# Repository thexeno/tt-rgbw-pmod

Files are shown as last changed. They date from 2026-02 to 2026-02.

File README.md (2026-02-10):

# tt-rgbw-pmod
An overkill PMOD to handle an RGBW LED for experimenting with the color rendering of the [thexeno/tt08-rgbw-controller](https://github.com/thexeno/tt08-rgbw-controller/ "tt08-rgbw-controller") ASIC. 
This PMOD matches with the [TinyTapeout/tt-demo-pcb](https://github.com/TinyTapeout/tt-demo-pcb "tt-demo-pcb"). These links are referred to as the "ASIC documentation".

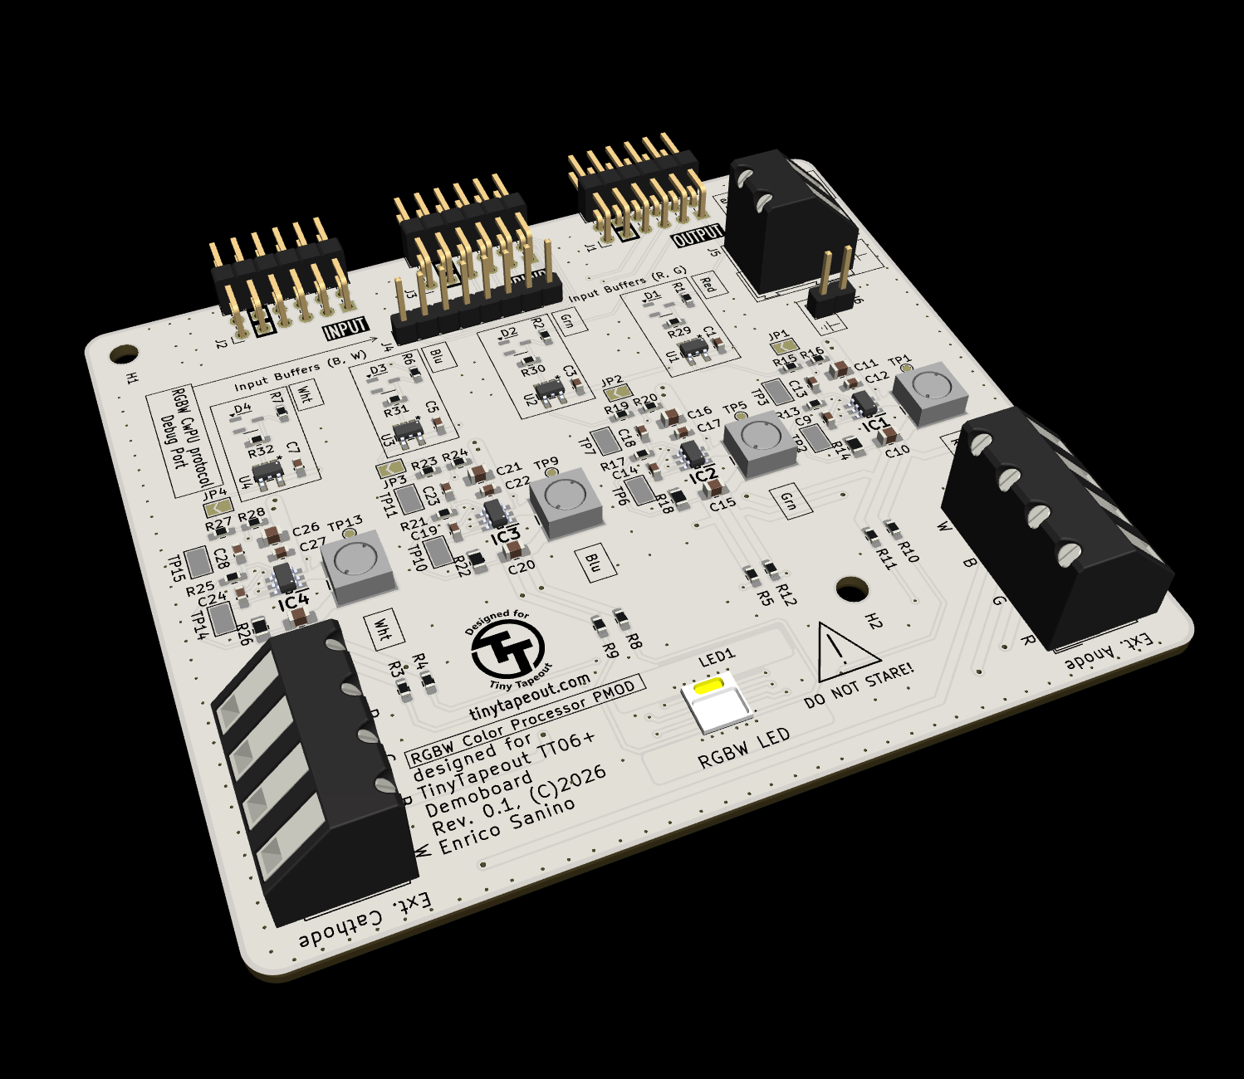
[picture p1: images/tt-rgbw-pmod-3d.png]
tt-rgbw-pmod board The RGBW PMOD board


### <p align="center"> PREVIEW: https://www.youtube.com/watch?v=X-74kIeId4A </p>

  <div align="center">
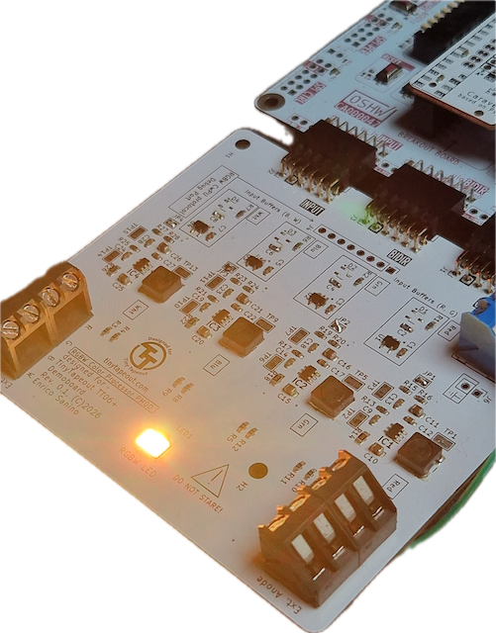
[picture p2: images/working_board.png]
  
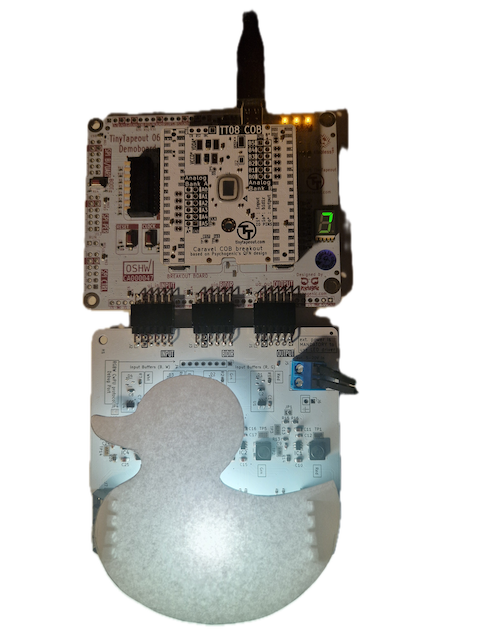
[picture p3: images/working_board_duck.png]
  
  <br>
  </div>

## Overview

This PMOD board provides high-power LED driver capabilities for the tt08-rgbw-controller ASIC, featuring four independent channels for RGBW LED control with both digital PWM and analog dimming modes.

## Pinout

### PWM inputs (inputs PMOD side, outputs ASIC side)

| Pmod | TinyTapeout | Function | Note |
|---|---|---|---|
| OUTPUT1 | uo[0] | Red PWM input | Input impedance 100 kΩ|
| OUTPUT2 | uo[1] | Green PWM input | Input impedance 100 kΩ|
| OUTPUT3 | uo[2] | Blue PWM input  | Input impedance 100 kΩ|
| OUTPUT4 | uo[3] | White PWM input | Input impedance 100 kΩ|
| OUTPUT5 - 8 | uo[4:7] | Not connected | |

### Inputs ASIC side

All "INPUT" pins are disconnected on the PMOD, not used. But the ASIC and the Demoboard are using them for the SPI communication, so signals are present if probed. See ASIC documentation.

### Colorwheel Debug Port

This applies only if enabled, see ASIC documentation.

| Pmod | TinyTapeout | Function | Note |
|---|---|---|---|
| BIDIR1 | uio_out[0] | CwPU register bit 0 |  |
| BIDIR2 | uio_out[1] | CwPU register bit 1 | |
| BIDIR3 | uio_out[2] | CwPU register bit 2  | |
| BIDIR4 | uio_out[3] | CwPU register bit 3 | |
| BIDIR5 | uio_out[4] | CwPU register bit 4 | |
| BIDIR6 | uio_out[5] | CwPU register bit 5 | |
| BIDIR7 | uio_out[6] | CwPU register bit 6 | |
| BIDIR8 | uio_out[7] | CwPU register bit 7 | |

## Getting Started

### Quick Setup Checklist

1. Select the control mode for each color channel using jumpers JP1–JP4:
  - Jumper bridged: Analog (LED-side) dimming mode
  - Jumper open: Digital (LED-side) PWM mode
2. Verify 3.3V power is available on the Demoboard's PMOD connector.
3. Connect the RGBW Color Processor board to the Demoboard.
4. Apply external power: Connect 6–20V to J4 or J5 (minimum 5V required to activate drivers).

### Using External LEDs

To use external LEDs instead of the onboard ones, open the following jumper connections:
- R3, R4, R5, R8, R9, R10, R11, R12

### Current Adjustment

Adjust the constant-current output via resistors:
- R14 (Red channel)
- R18 (Green channel)
- R22 (Blue channel)
- R26 (White channel)

Current calculation:
- Digital dimming mode: I = 0.1V / R (default: 75 mA)
- Analog dimming mode: I = 0.2V / R (default: 150 mA)

## Operating Modes

### Digital PWM Mode (Jumper Open)
- PWM PMOD pin frequency: < 1 kHz
- Lower current consumption
- Suitable for most applications

### Analog Dimming Mode (Jumper Bridged)
- PWM PMOD pin frequency: > 10 kHz (recommended: 50 kHz)
- Higher current capability
- For continuous operation at default settings (150 mA per channel), a small heatsink is recommended:
  - Base size: 7×7 mm
  - Thermal resistance: 30–40 °C/W
 
## Debugging Features

Breakout to CwPU protocol 8-bit interface for internal registers probing. This is active only if enabled. See ASIC documentation.

## Electrical Characteristics

| Parameter | Min | Typ | Max | Unit | Notes |
|---|-----|-----|-----|---|---|
| External supply voltage | 6 | 12  | 20  | V | Required (J4 or J5) |
| External supply current | - | - | 400 | mA  | 2W total max |
| PMOD Logic VDD | 3.0 | - | 5.0 | V  | To handle correctly analog or digital dimming detection |
| Logic input voltage | - | 3.3 | - | V | TTL compatible |
| LED current (Digital mode) | - | 75  | - | mA | Per channel, default |
| LED current (Analog mode) | - | 150 | - | mA | Per channel, default |
| PWM input for Digital mode | - | - | 1 | kHz  | Maximum recommended |
| PWM input for Analog mode | 10  | 50  | - | kHz  | Minimum / recommended |
| V<sub>IL</sub> | -  | 0.8  | - | V  | LVTTL |
| V<sub>IH</sub> | -  | 2.0  | - | V  | LVTTL |

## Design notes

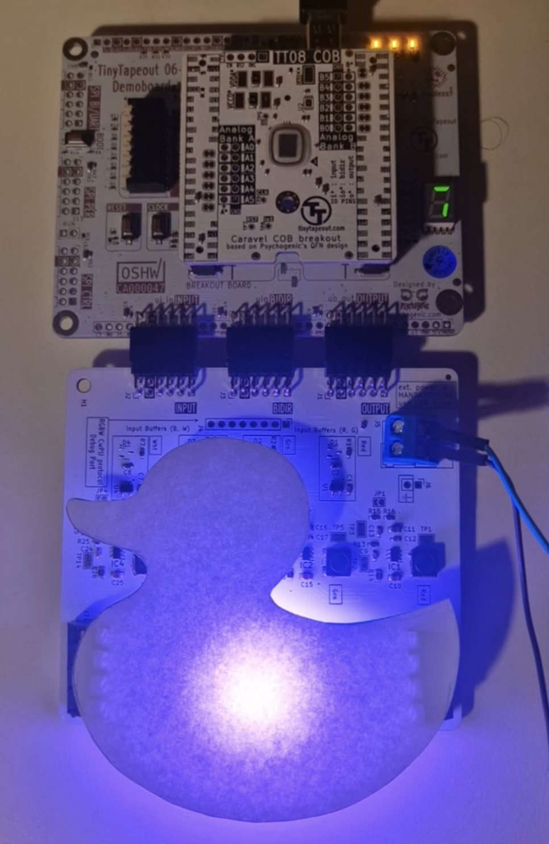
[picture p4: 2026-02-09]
images/pmod_demo_snap.png

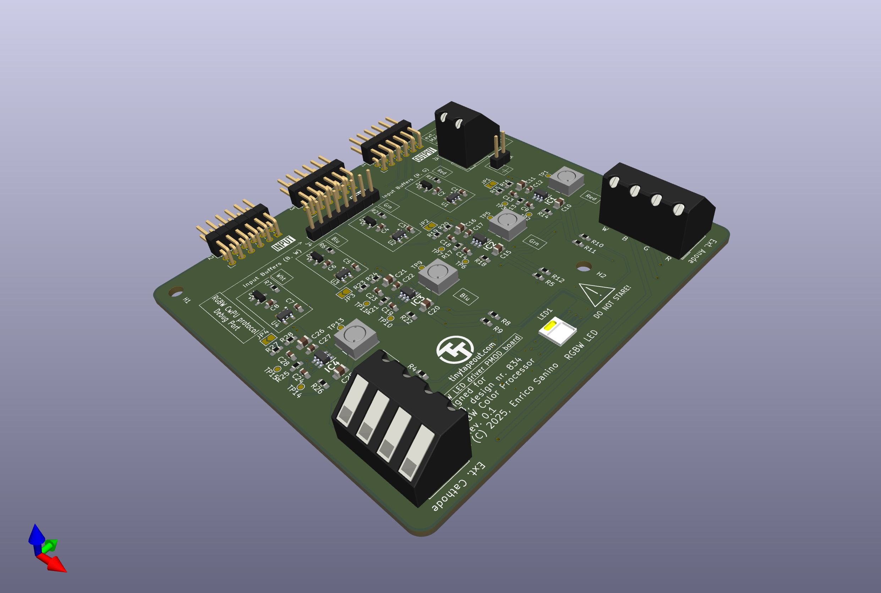
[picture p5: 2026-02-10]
rgbw_pmod/rgbw_pmod.png

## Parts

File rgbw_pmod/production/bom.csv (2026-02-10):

Designator | Footprint | Quantity | Value | LCSC Part #
C1, C12, C14, C17, C19, C22, C24, C27, C3, C5, C7, C9 | 0603 | 12 | 100n
C10, C11, C15, C16, C20, C21, C25, C26 | 0805 | 8 | 10u
C13, C18, C23, C28 | 0603 | 4 | 82n
C2, C4, C6, C8 | 0603 | 4 | 10n
D1, D2, D3, D4 | SOT-23-3 | 4 | BZX84Cxx
IC1, IC2, IC3, IC4 | SOT95P280X110-6N | 4 | TPS54201DDCR
J1, J2, J3 | PinHeader_2x06_P2.54mm_PMODPeriph2B | 3 | PMOD | C492434
J4 | PinHeader_1x08_P2.54mm_Vertical | 1 | Conn_01x08_Pin
J5 | TerminalBlock_Altech_AK300-2_P5.00mm | 1 | Screw_Terminal_01x02
J6 | PinHeader_1x02_P2.54mm_Vertical | 1 | Conn_01x02_Pin
J7, J8 | Altech_AK100_1x04_P5.00mm | 2 | Screw_Terminal_01x04
L1, L2, L3, L4 | IND_BOURNS_SRR5028 | 4 | 150uH
LED1 | L1MCRGB3080500MP0 | 1 | L1MC-RGB3080500MP0
R1, R2, R6, R7 | 0603 | 4 | 220
R10, R11, R12, R3, R4, R5, R8, R9 | 0603 | 8 | 0
R13, R17, R21, R25 | 0603 | 4 | 910
R14, R18, R22, R26 | 0805 | 4 | 1.33
R15, R19, R23, R27 | 0603 | 4 | 100k
R16, R20, R24, R28 | 0603 | 4 | 54.9k
TP1, TP10, TP11, TP13, TP14, TP15, TP2, TP3, TP5, TP6, TP7, TP9 | TestPoint_Keystone_5015_Micro_Mini | 12 | TestPoint
U1, U2, U3, U4 | SOT95P275X110-5N | 4 | MC74VHC1GT50DBVT1G | MC74VHC1GT50DTT1

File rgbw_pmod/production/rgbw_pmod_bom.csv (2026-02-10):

Reference | Value | Datasheet | Footprint | Qty | DNP
C1,C3,C5,C7,C9,C12,C14,C17,C19,C22,C24,C27 | 100n | ~ | Capacitor_SMD:C_0603_1608Metric_Pad1.08x0.95mm_HandSolder | 12
C2,C4,C6,C8 | 10n | ~ | Capacitor_SMD:C_0603_1608Metric_Pad1.08x0.95mm_HandSolder | 4
C10,C11,C15,C16,C20,C21,C25,C26 | 10u | ~ | Capacitor_SMD:C_0805_2012Metric_Pad1.18x1.45mm_HandSolder | 8
C13,C18,C23,C28 | 82n | ~ | Capacitor_SMD:C_0603_1608Metric_Pad1.08x0.95mm_HandSolder | 4
D1,D2,D3,D4 | BZX84Cxx | https://diotec.com/tl_files/diotec/files/pdf/datasheets/bzx84c2v4.pdf | Package_TO_SOT_SMD:SOT-23-3 | 4
IC1,IC2,IC3,IC4 | TPS54201DDCR | http://www.ti.com/lit/gpn/TPS54201 | TPS54201DDCR:SOT95P280X110-6N | 4
J1,J2,J3 | PMOD | https://cdn.amphenol-cs.com/media/wysiwyg/files/drawing/10129382.pdf | TinyTapeout_PMOD:PinHeader_2x06_P2.54mm_PMODPeriph2B | 3
J4 | Conn_01x08_Pin | ~ | Connector_PinHeader_2.54mm:PinHeader_1x08_P2.54mm_Vertical | 1
J5 | Screw_Terminal_01x02 | ~ | TerminalBlock:TerminalBlock_Altech_AK300-2_P5.00mm | 1
J6 | Conn_01x02_Pin | ~ | Connector_PinHeader_2.54mm:PinHeader_1x02_P2.54mm_Vertical | 1
J7,J8 | Screw_Terminal_01x04 | ~ | TerminalBlock_Altech:Altech_AK100_1x04_P5.00mm | 2
L1,L2,L3,L4 | 150uH | ~ | SRR5028:IND_BOURNS_SRR5028 | 4
LED1 | L1MC-RGB3080500MP0 | https://componentsearchengine.com/Datasheets/1/L1MC-RGB3080500MP0.pdf | L1MC-RGB3080500MP0:L1MCRGB3080500MP0 | 1
R1,R2,R6,R7 | 220 | ~ | Resistor_SMD:R_0603_1608Metric_Pad0.98x0.95mm_HandSolder | 4
R3,R4,R5,R8,R9,R10,R11,R12 | 0 | ~ | Resistor_SMD:R_0603_1608Metric_Pad0.98x0.95mm_HandSolder | 8
R13,R17,R21,R25 | 910 | ~ | Resistor_SMD:R_0603_1608Metric_Pad0.98x0.95mm_HandSolder | 4
R14,R18,R22,R26 | 1.33 | ~ | Resistor_SMD:R_0603_1608Metric_Pad0.98x0.95mm_HandSolder | 4
R15,R19,R23,R27 | 100k | ~ | Resistor_SMD:R_0603_1608Metric_Pad0.98x0.95mm_HandSolder | 4
R16,R20,R24,R28 | 54.9k | ~ | Resistor_SMD:R_0603_1608Metric_Pad0.98x0.95mm_HandSolder | 4
TP1,TP2,TP3,TP4,TP5,TP6,TP7,TP8,TP9,TP10,TP11,TP12,TP13,TP14,TP15,TP16 | TestPoint | ~ | TestPoint:TestPoint_Pad_D1.0mm | 16
U1,U2,U3,U4 | MC74VHC1GT50DTT1 |  | MC74VHC1GT50DTT1:SOT95P275X110-5N | 4

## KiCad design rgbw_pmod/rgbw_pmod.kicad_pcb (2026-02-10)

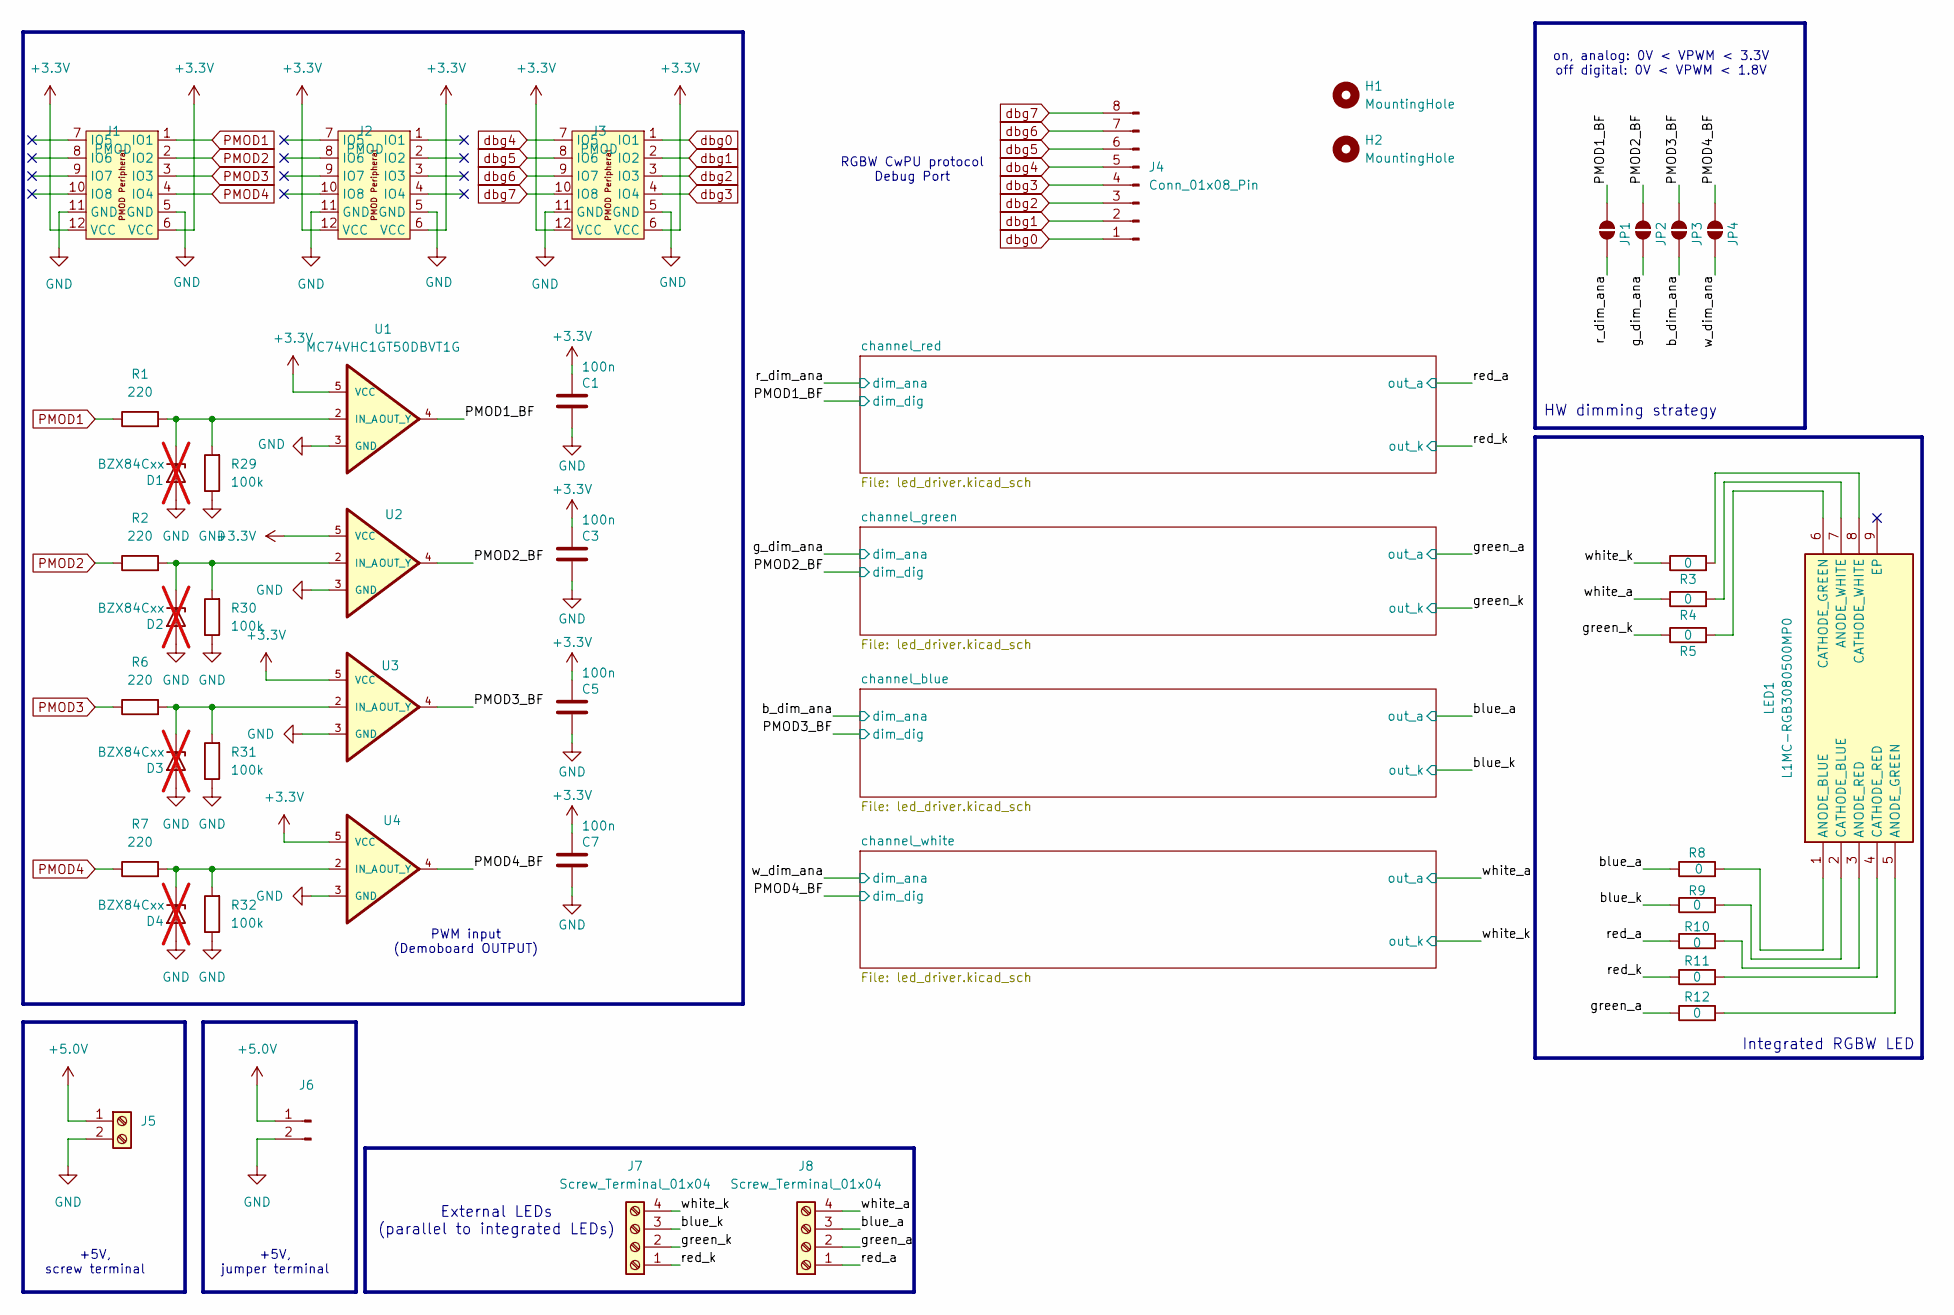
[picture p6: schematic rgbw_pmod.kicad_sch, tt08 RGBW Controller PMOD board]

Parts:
C1, C3, C5, C7: 100n; C_0603_1608Metric_Pad1.08x0.95mm_HandSolder
D1, D2, D3, D4: BZX84Cxx; SOT-23-3; not fitted
H1, H2: MountingHole; MountingHole_3.2mm_M3_ISO7380
J1, J2, J3: PMOD; PinHeader_2x06_P2.54mm_PMODPeriph2B; MPN 826634-6; LCSC C2935938
J4: Conn_01x08_Pin; PinHeader_1x08_P2.54mm_Vertical
J5: Screw_Terminal_01x02; TerminalBlock_Altech_AK300-2_P5.00mm
J6: Conn_01x02_Pin; PinHeader_1x02_P2.54mm_Vertical
J7, J8: Screw_Terminal_01x04; Altech_AK100_1x04_P5.00mm
JP1, JP2, JP3, JP4: SolderJumper_2_Open; SolderJumper-2_P1.3mm_Open_TrianglePad1.0x1.5mm
LED1: L1MC-RGB3080500MP0; L1MCRGB3080500MP0; Mouser Part Number 997-L1MCRGB3080500MP
R1, R2, R6, R7: 220; R_0603_1608Metric_Pad0.98x0.95mm_HandSolder
R3, R4, R5, R8, R9, R10, R11, R12: 0; R_0603_1608Metric_Pad0.98x0.95mm_HandSolder
R29, R30, R31, R32: 100k; R_0603_1608Metric_Pad0.98x0.95mm_HandSolder
U1, U2, U3, U4: MC74VHC1GT50DBVT1G; SOT95P275X110-5N; MPN MC74VHC1GT50DTT1

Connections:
+3.3V: C1.1, C3.1, C5.1, C7.1, J1.6 (VCC), J1.12 (VCC), J2.6 (VCC), J2.12 (VCC), J3.6 (VCC), J3.12 (VCC), U1.5 (VCC), U2.5 (VCC), U3.5 (VCC), U4.5 (VCC)
+5.0V: J5.1, J6.1; also elsewhere on the board
/PMOD1_BF: JP1.2 (B), U1.4 (OUT_Y); also elsewhere on the board
/PMOD2_BF: JP2.2 (B), U2.4 (OUT_Y); also elsewhere on the board
/PMOD3_BF: JP3.2 (B), U3.4 (OUT_Y); also elsewhere on the board
/PMOD4_BF: JP4.2 (B), U4.4 (OUT_Y); also elsewhere on the board
/b_dim_ana: JP3.1 (A); also elsewhere on the board
/blue_a: J8.3, R8.1; also elsewhere on the board
/blue_k: J7.3, R9.1; also elsewhere on the board
/g_dim_ana: JP2.1 (A); also elsewhere on the board
/green_a: J8.2, R12.1; also elsewhere on the board
/green_k: J7.2, R5.1; also elsewhere on the board
/r_dim_ana: JP1.1 (A); also elsewhere on the board
/red_a: J8.1, R10.1; also elsewhere on the board
/red_k: J7.1, R11.1; also elsewhere on the board
/w_dim_ana: JP4.1 (A); also elsewhere on the board
/white_a: J8.4, R4.1; also elsewhere on the board
/white_k: J7.4, R3.1; also elsewhere on the board
GND: C1.2, C3.2, C5.2, C7.2, D1.1 (A), D2.1 (A), D3.1 (A), D4.1 (A), J1.5 (GND), J1.11 (GND), J2.5 (GND), J2.11 (GND), J3.5 (GND), J3.11 (GND), J5.2, J6.2, R29.1, R30.1, R31.1, R32.1, U1.3 (GND), U2.3 (GND), U3.3 (GND), U4.3 (GND); also elsewhere on the board
unnamed: D1.3 (K), R1.2, R29.2, U1.2 (IN_A)
unnamed: D2.3 (K), R2.2, R30.2, U2.2 (IN_A)
unnamed: D3.3 (K), R6.2, R31.2, U3.2 (IN_A)
unnamed: D4.3 (K), R7.2, R32.2, U4.2 (IN_A)
unnamed: LED1.1 (ANODE_BLUE), R8.2
unnamed: LED1.5 (ANODE_GREEN), R12.2
unnamed: LED1.3 (ANODE_RED), R10.2
unnamed: LED1.7 (ANODE_WHITE), R4.2
unnamed: LED1.2 (CATHODE_BLUE), R9.2
unnamed: LED1.6 (CATHODE_GREEN), R5.2
unnamed: LED1.4 (CATHODE_RED), R11.2
unnamed: LED1.8 (CATHODE_WHITE), R3.2
PMOD1: J1.1 (IO1), R1.1
PMOD2: J1.2 (IO2), R2.1
PMOD3: J1.3 (IO3), R6.1
PMOD4: J1.4 (IO4), R7.1
dbg0: J3.1 (IO1), J4.1
dbg1: J3.2 (IO2), J4.2
dbg2: J3.3 (IO3), J4.3
dbg3: J3.4 (IO4), J4.4
dbg4: J3.7 (IO5), J4.5
dbg5: J3.8 (IO6), J4.6
dbg6: J3.9 (IO7), J4.7
dbg7: J3.10 (IO8), J4.8

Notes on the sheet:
on, analog: 0V < VPWM < 3.3V off digital: 0V < VPWM < 1.8V
Integrated RGBW LED
+5V, screw terminal
External LEDs (parallel to integrated LEDs)
PWM input (Demoboard OUTPUT)
+5V, jumper terminal
HW dimming strategy
RGBW CwPU protocol Debug Port

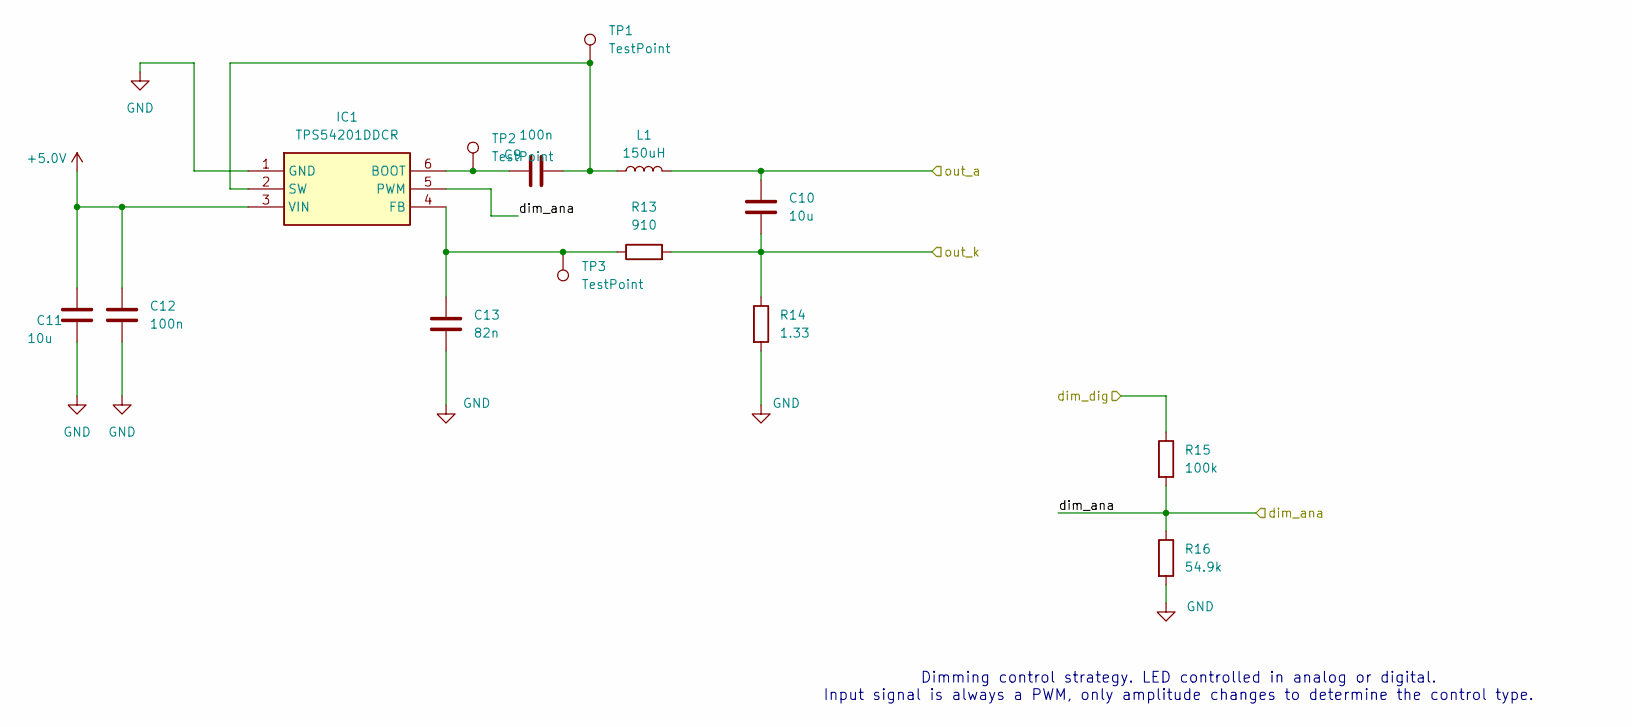
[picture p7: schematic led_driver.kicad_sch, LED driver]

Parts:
C9, C12: 100n; C_0603_1608Metric_Pad1.08x0.95mm_HandSolder
C10, C11: 10u; C_0805_2012Metric_Pad1.18x1.45mm_HandSolder
C13: 82n; C_0603_1608Metric_Pad1.08x0.95mm_HandSolder
IC1: TPS54201DDCR; SOT95P280X110-6N; Mouser Part Number 595-TPS54201DDCR
L1: 150uH; IND_BOURNS_SRR5028
R13: 910; R_0603_1608Metric_Pad0.98x0.95mm_HandSolder
R14: 1.33; R_0805_2012Metric_Pad1.20x1.40mm_HandSolder
R15: 100k; R_0603_1608Metric_Pad0.98x0.95mm_HandSolder
R16: 54.9k; R_0603_1608Metric_Pad0.98x0.95mm_HandSolder
TP1: TestPoint; TestPoint_Pad_D1.0mm
TP2, TP3: TestPoint; TestPoint_Keystone_5015_Micro_Mini

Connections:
+5.0V: C11.1, C12.1, IC1.3 (VIN); also elsewhere on the board
/PMOD1_BF: R15.1; also elsewhere on the board
/r_dim_ana: IC1.5 (PWM), R15.2, R16.1; also elsewhere on the board
/red_a: C10.1, L1.2; also elsewhere on the board
/red_k: C10.2, R13.2, R14.1; also elsewhere on the board
GND: C11.2, C12.2, C13.1, IC1.1 (GND), R14.2, R16.2; also elsewhere on the board
unnamed: C9.1, IC1.6 (BOOT), TP2.1
unnamed: C13.2, IC1.4 (FB), R13.1, TP3.1
unnamed: C9.2, IC1.2 (SW), L1.1, TP1.1

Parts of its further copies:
C14, C17, C19, C22, C24, C27: 100n; C_0603_1608Metric_Pad1.08x0.95mm_HandSolder
C15, C16, C20, C21, C25, C26: 10u; C_0805_2012Metric_Pad1.18x1.45mm_HandSolder
C18, C23, C28: 82n; C_0603_1608Metric_Pad1.08x0.95mm_HandSolder
IC2, IC3, IC4: TPS54201DDCR; SOT95P280X110-6N; Mouser Part Number 595-TPS54201DDCR
L2, L3, L4: 150uH; IND_BOURNS_SRR5028
R17, R21, R25: 910; R_0603_1608Metric_Pad0.98x0.95mm_HandSolder
R18, R22, R26: 1.33; R_0805_2012Metric_Pad1.20x1.40mm_HandSolder
R19, R23, R27: 100k; R_0603_1608Metric_Pad0.98x0.95mm_HandSolder
R20, R24, R28: 54.9k; R_0603_1608Metric_Pad0.98x0.95mm_HandSolder
TP5, TP9, TP13: TestPoint; TestPoint_Pad_D1.0mm
TP6, TP7, TP10, TP11, TP14, TP15: TestPoint; TestPoint_Keystone_5015_Micro_Mini

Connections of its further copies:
+5.0V: C16.1, C17.1, C21.1, C22.1, C26.1, C27.1, IC2.3 (VIN), IC3.3 (VIN), IC4.3 (VIN); also elsewhere on the board
/PMOD2_BF: R19.1; also elsewhere on the board
/PMOD3_BF: R23.1; also elsewhere on the board
/PMOD4_BF: R27.1; also elsewhere on the board
/b_dim_ana: IC3.5 (PWM), R23.2, R24.1; also elsewhere on the board
/blue_a: C20.1, L3.2; also elsewhere on the board
/blue_k: C20.2, R21.2, R22.1; also elsewhere on the board
/g_dim_ana: IC2.5 (PWM), R19.2, R20.1; also elsewhere on the board
/green_a: C15.1, L2.2; also elsewhere on the board
/green_k: C15.2, R17.2, R18.1; also elsewhere on the board
/w_dim_ana: IC4.5 (PWM), R27.2, R28.1; also elsewhere on the board
/white_a: C25.1, L4.2; also elsewhere on the board
/white_k: C25.2, R25.2, R26.1; also elsewhere on the board
GND: C16.2, C17.2, C18.1, C21.2, C22.2, C23.1, C26.2, C27.2, C28.1, IC2.1 (GND), IC3.1 (GND), IC4.1 (GND), R18.2, R20.2, R22.2, R24.2, R26.2, R28.2; also elsewhere on the board
unnamed: C14.1, IC2.6 (BOOT), TP6.1
unnamed: C18.2, IC2.4 (FB), R17.1, TP7.1
unnamed: C14.2, IC2.2 (SW), L2.1, TP5.1
unnamed: C19.1, IC3.6 (BOOT), TP10.1
unnamed: C23.2, IC3.4 (FB), R21.1, TP11.1
unnamed: C19.2, IC3.2 (SW), L3.1, TP9.1
unnamed: C24.1, IC4.6 (BOOT), TP14.1
unnamed: C28.2, IC4.4 (FB), R25.1, TP15.1
unnamed: C24.2, IC4.2 (SW), L4.1, TP13.1

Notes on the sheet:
Dimming control strategy. LED controlled in analog or digital. Input signal is always a PWM, only amplitude changes to determine the control type.

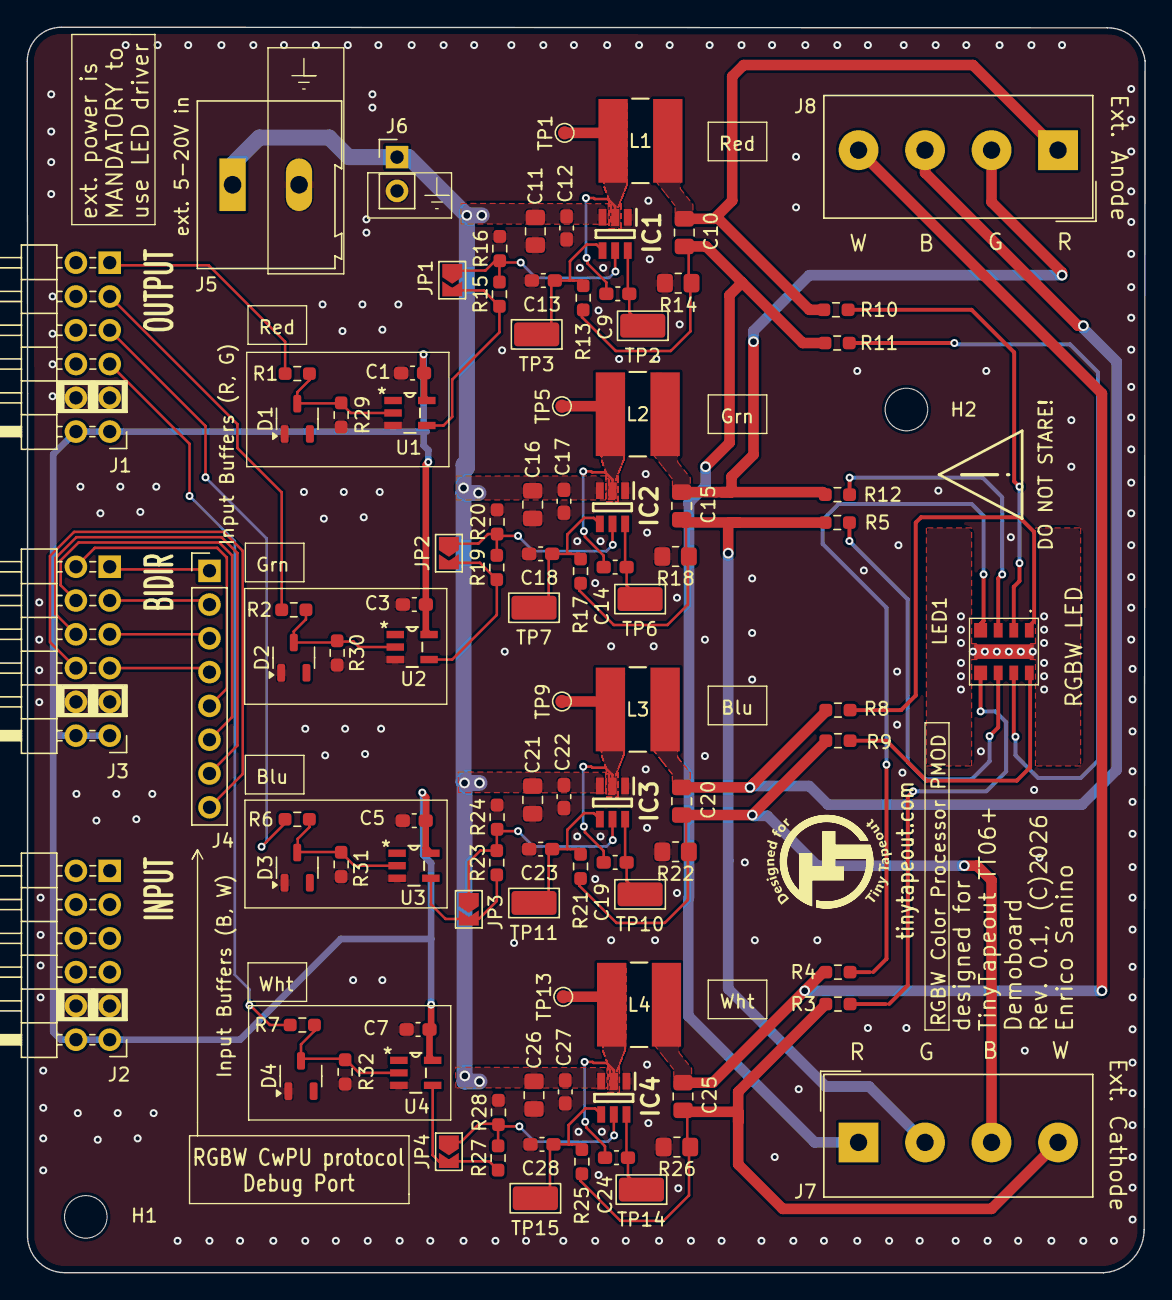
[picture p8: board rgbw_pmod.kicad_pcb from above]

Board: 2 copper layers, 84.0 x 93.6 mm, 101 parts (1 on the bottom side), 55 nets.

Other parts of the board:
LOGO1: PMOD_LOGO; TT_PMOD_Logo_7mm
LOGO2: KiCad-Logo2_5mm_SilkScreen

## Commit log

2026-02-05 Add images and update README with board illustration
2026-02-09 Update README with new pinout and debugging features (incomplete)
    Added additional PWM inputs and Colorwheel Debug Port information to the README.
2026-02-09 Update PWM inputs section in README.md
2026-02-10 KiCad design files and libs
    [bom.csv, designators.csv, positions.csv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]
2026-02-10 remaining KiCad files
    [calcs.xlsx, led_driver.kicad_sch, rgbw_pmod.kicad_pcb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]

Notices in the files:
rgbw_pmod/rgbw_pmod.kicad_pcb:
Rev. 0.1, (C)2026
